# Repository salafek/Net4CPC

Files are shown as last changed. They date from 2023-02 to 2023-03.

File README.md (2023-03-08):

# Net4CPC
Net4CPC is an Ethernet interface for the [Amstrad CPC](https://www.cpcwiki.eu/index.php/CPC) range of computers.</br>
It is a stand alone implemetation of the Ethernet interface found on the [Cyboard](https://github.com/salafek/cyboard-for-cpc).</br>
It is supported by [SymbOS](http://symbos.de) and by [KCNet utilities](https://github.com/salafek/KCNet-software-for-Net4CPC) for CP/M.</br> 
</br>
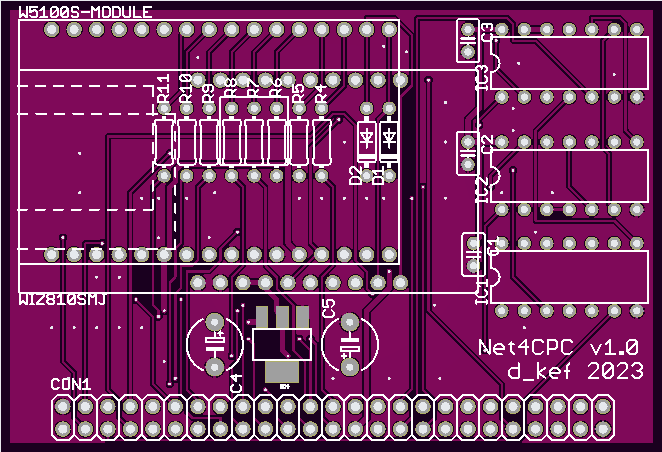
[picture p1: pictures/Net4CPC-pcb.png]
Net4CPC PCB

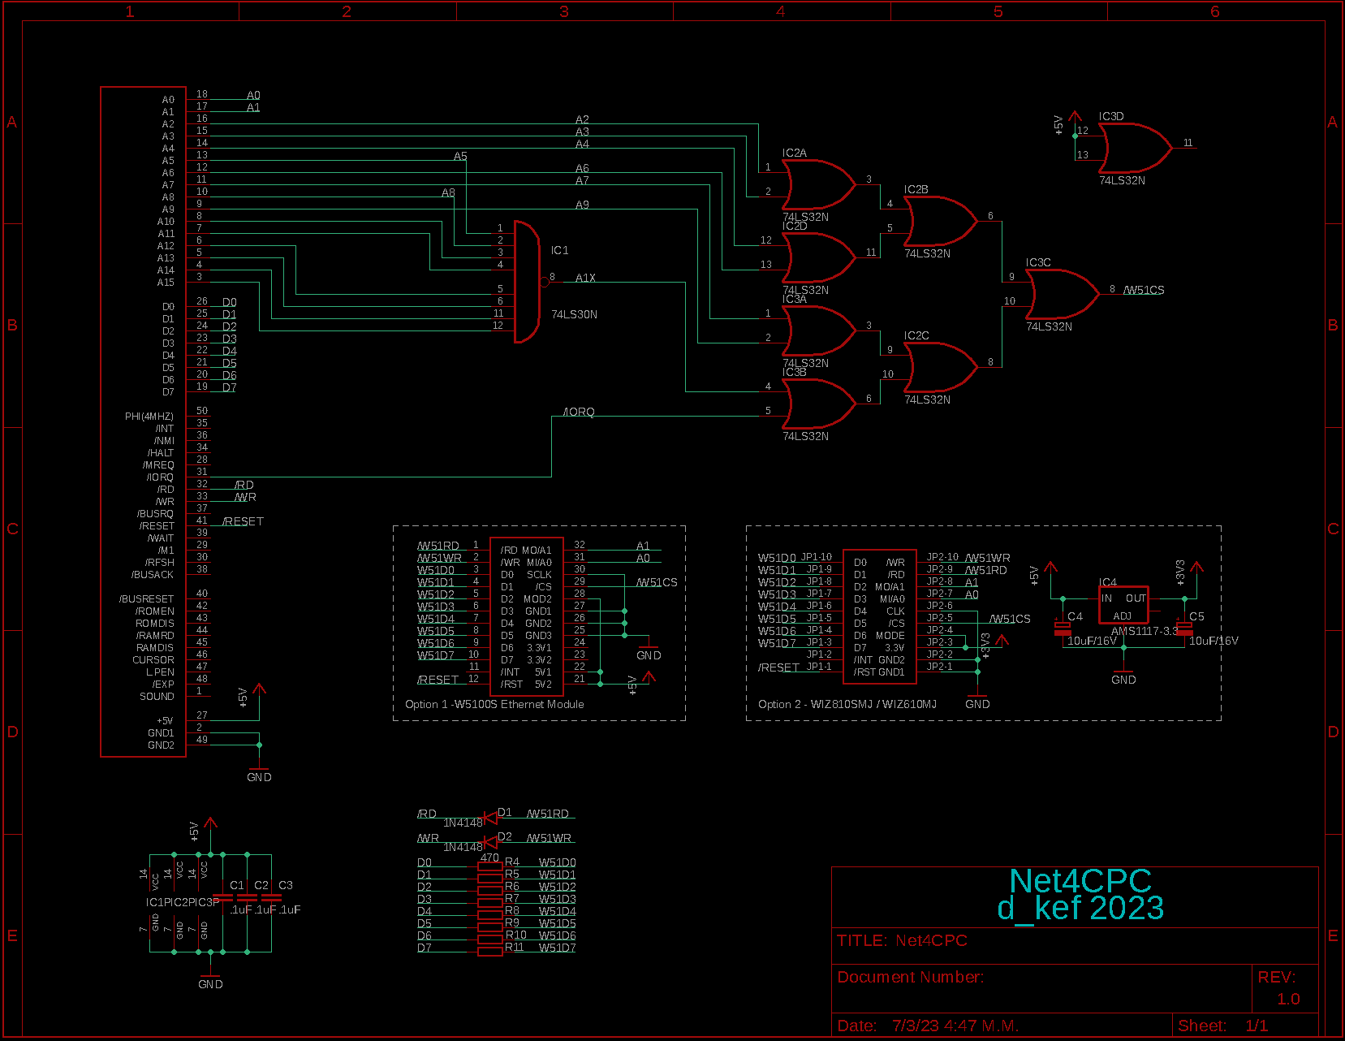
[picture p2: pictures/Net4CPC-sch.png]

## Notes
The interface has a [Mother X4](https://cpcrulez.fr/hardware-interface-mother_x4.htm) compatible connector.</br> 
The network module is based on the [WIZnet's W5100S](https://www.wiznet.io/product-item/w5100s/) embedded ethernet controller and works in indirect parallel bus mode.</br>
In this mode it needs 4 I/O ports:
- #FD20: MR - Common Register MR
- #FD21: IDM_ARH - Upper 8 bits Offset Address Register
- #FD22: IDM_ARL - Lower 8 bits Offset Address Register
- #FD23: IDM_DR - 8 Bits Data Register

A detailed description on how to program the module, with flow diagrams and programming examples, can be found at the WIZnet's official site:</br>
[W5100S TCP Function](https://docs.wiznet.io/Product/iEthernet/W5100S/Application-Note/tcp)</br>
[W5100S UDP Function](https://docs.wiznet.io/Product/iEthernet/W5100S/Application-Note/udp)</br>
[SOCKET-less Command](https://docs.wiznet.io/Product/iEthernet/W5100S/Application-Note/socket-less-command)</br>

The PCB has provision for 2 differrent types of Ethernet modules:
- A Chinese [W5100S module](https://www.aliexpress.com/w/wholesale-%22W5100S-Network-Module%22-parallel.html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) with an integrated 3.3V regulator.</br> W5100S module
- The original WIZnet's [W5100S](https://github.com/Wiznet/Hardware-Files-of-WIZnet/tree/master/05_Network_Module/WIZ810SMJ) or [W6100](https://github.com/Wiznet/Hardware-Files-of-WIZnet/tree/master/05_Network_Module/WIZ610MJ) modules.</br> 
## Build info
The schematic and layout were generated with Autodesk EAGLE 9.6.2 free edition</br>

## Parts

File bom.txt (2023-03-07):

Partlist

Part          Value                 Package               Digi-Key PN

C1            .1uF                  C025/C320             399-9871-1-ND
C2            .1uF                  C025/C320             399-9871-1-ND
C3            .1uF                  C025/C320             399-9871-1-ND
C4            10uF/16V              E5-06                 B41827A4105M-ND
C5            10uF/16V              E5-06                 B41827A4105M-ND
CON1          CPCBUS                HEADER R/A 50POS      732-5414-ND
D1            1N4148                DO35-7                2368-1N4148-ND
D2            1N4148                DO35-7                2368-1N4148-ND
IC1           74LS30N               DIL14                 296-3693-5-ND
IC2           74LS32N               DIL14                 296-1658-5-ND
IC3           74LS32N               DIL14                 296-1658-5-ND
IC4           AMS1117-3.3           SOT-223               4518-AMS1117-3.3TR-ND
R4            470                   0204/0207             MFR-25FRF52-470R-ND
R5            470                   0204/0207             MFR-25FRF52-470R-ND
R6            470                   0204/0207             MFR-25FRF52-470R-ND
R7            470                   0204/0207             MFR-25FRF52-470R-ND
R8            470                   0204/0207             MFR-25FRF52-470R-ND
R9            470                   0204/0207             MFR-25FRF52-470R-ND
R10           470                   0204/0207             MFR-25FRF52-470R-ND
R11           470                   0204/0207             MFR-25FRF52-470R-ND
W5100S-MODULE W5100S-NETWORK-MODULE W5100S-NETWORK-MODULE -
WIZ810SMJ     WIZ810SMJ / WIZ610MJ  WIZ810SMJ / WIZ610MJ  -

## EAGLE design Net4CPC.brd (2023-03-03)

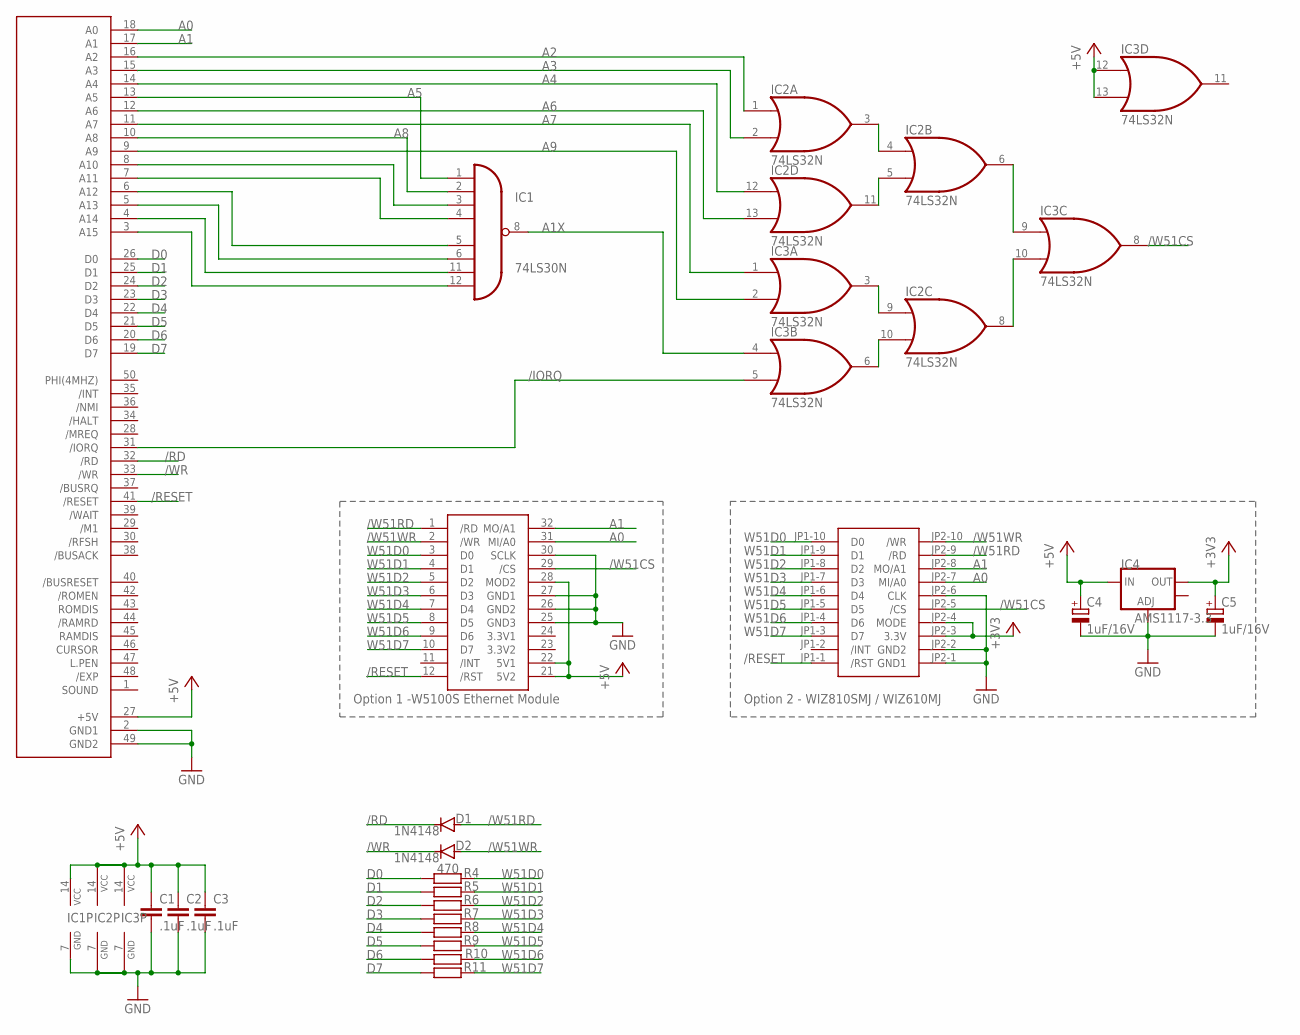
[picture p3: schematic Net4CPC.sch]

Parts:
C1, C2, C3: .1uF; C025-025X050
C4, C5: 1uF/16V; E5-6
CON1: CPCBUS; 2X25
D1, D2: 1N4148; DO35-7
IC1: 74LS30N; DIL14
IC2, IC3: 74LS32N; DIL14
IC4: AMS1117-3.3; SOT223
R4, R5, R6, R7, R8, R9, R10, R11: 470; 0204/7
W5100S-MODULE: W5100S-NETWORK-MODULENO-NAMES; W5100S-NETWORK-MODULE-NO-NAMES
WIZ810SMJ: WIZ810SMJ-NETWORK-MODULENO-NAMES; WIZ810SMJ-NETWORK-MODULE-NO-NAMES

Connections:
3.3V1: W5100S-MODULE.24 (3.3V1)
3.3V2: W5100S-MODULE.23 (3.3V2)
+3V3: C5.+, IC4.2 (OUT), WIZ810SMJ.JP2-3 (3.3V), WIZ810SMJ.JP2-4 (MODE)
+5V: C1.1, C2.1, C3.1, C4.+, CON1.27 (+5V), IC1.14 (VCC), IC2.14 (VCC), IC3.12 (I0), IC3.13 (I1), IC3.14 (VCC), IC4.3 (IN), W5100S-MODULE.21 (5V2), W5100S-MODULE.22 (5V1), W5100S-MODULE.28 (MOD2)
/IORQ: CON1.31 (/IORQ), IC3.5 (I1)
/RD: CON1.32 (/RD), D1.C
/RESET: CON1.41 (/RESET), W5100S-MODULE.12 (/RST), WIZ810SMJ.JP1-1 (/RST)
/W51CS: IC3.8 (O), W5100S-MODULE.29 (/CS), WIZ810SMJ.JP2-5 (/CS)
/W51RD: D1.A, W5100S-MODULE.1 (/RD), WIZ810SMJ.JP2-9 (/RD)
/W51WR: D2.A, W5100S-MODULE.2 (/WR), WIZ810SMJ.JP2-10 (/WR)
/WR: CON1.33 (/WR), D2.C
A0: CON1.18 (A0), W5100S-MODULE.31 (MI/A0), WIZ810SMJ.JP2-7 (MI/A0)
A1: CON1.17 (A1), W5100S-MODULE.32 (MO/A1), WIZ810SMJ.JP2-8 (MO/A1)
A1X: IC1.8 (O), IC3.4 (I0)
A2: CON1.16 (A2), IC2.1 (I0)
A3: CON1.15 (A3), IC2.2 (I1)
A4: CON1.14 (A4), IC2.12 (I0)
A5: CON1.13 (A5), IC1.1 (I0)
A6: CON1.12 (A6), IC2.13 (I1)
A7: CON1.11 (A7), IC3.1 (I0)
A8: CON1.10 (A8), IC1.2 (I1)
A9: CON1.9 (A9), IC3.2 (I1)
A10: CON1.8 (A10), IC1.3 (I2)
A11: CON1.7 (A11), IC1.4 (I3)
A12: CON1.6 (A12), IC1.5 (I4)
A13: CON1.5 (A13), IC1.6 (I5)
D0: CON1.26 (D0), R4.1
D1: CON1.25 (D1), R5.1
D2: CON1.24 (D2), R6.1
D3: CON1.23 (D3), R7.1
D4: CON1.22 (D4), R8.1
D5: CON1.21 (D5), R9.1
D6: CON1.20 (D6), R10.1
D7: CON1.19 (D7), R11.1
GND: C1.2, C2.2, C3.2, C4.-, C5.-, CON1.2 (GND1), CON1.49 (GND2), IC1.7 (GND), IC2.7 (GND), IC3.7 (GND), IC4.1 (ADJ), W5100S-MODULE.25 (GND3), W5100S-MODULE.26 (GND2), W5100S-MODULE.27 (GND1), W5100S-MODULE.30 (SCLK), WIZ810SMJ.JP2-1 (GND1), WIZ810SMJ.JP2-2 (GND2), WIZ810SMJ.JP2-6 (CLK)
unnamed: CON1.3 (A15), IC1.12 (I7)
unnamed: CON1.4 (A14), IC1.11 (I6)
unnamed: IC2.3 (O), IC2.4 (I0)
unnamed: IC2.5 (I1), IC2.11 (O)
unnamed: IC2.9 (I0), IC3.3 (O)
unnamed: IC2.10 (I1), IC3.6 (O)
unnamed: IC2.6 (O), IC3.9 (I0)
unnamed: IC2.8 (O), IC3.10 (I1)
W51D0: R4.2, W5100S-MODULE.3 (D0), WIZ810SMJ.JP1-10 (D0)
W51D1: R5.2, W5100S-MODULE.4 (D1), WIZ810SMJ.JP1-9 (D1)
W51D2: R6.2, W5100S-MODULE.5 (D2), WIZ810SMJ.JP1-8 (D2)
W51D3: R7.2, W5100S-MODULE.6 (D3), WIZ810SMJ.JP1-7 (D3)
W51D4: R8.2, W5100S-MODULE.7 (D4), WIZ810SMJ.JP1-6 (D4)
W51D5: R9.2, W5100S-MODULE.8 (D5), WIZ810SMJ.JP1-5 (D5)
W51D6: R10.2, W5100S-MODULE.9 (D6), WIZ810SMJ.JP1-4 (D6)
W51D7: R11.2, W5100S-MODULE.10 (D7), WIZ810SMJ.JP1-3 (D7)

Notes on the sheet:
Option 1 -W5100S Ethernet Module
Option 2 - WIZ810SMJ / WIZ610MJ

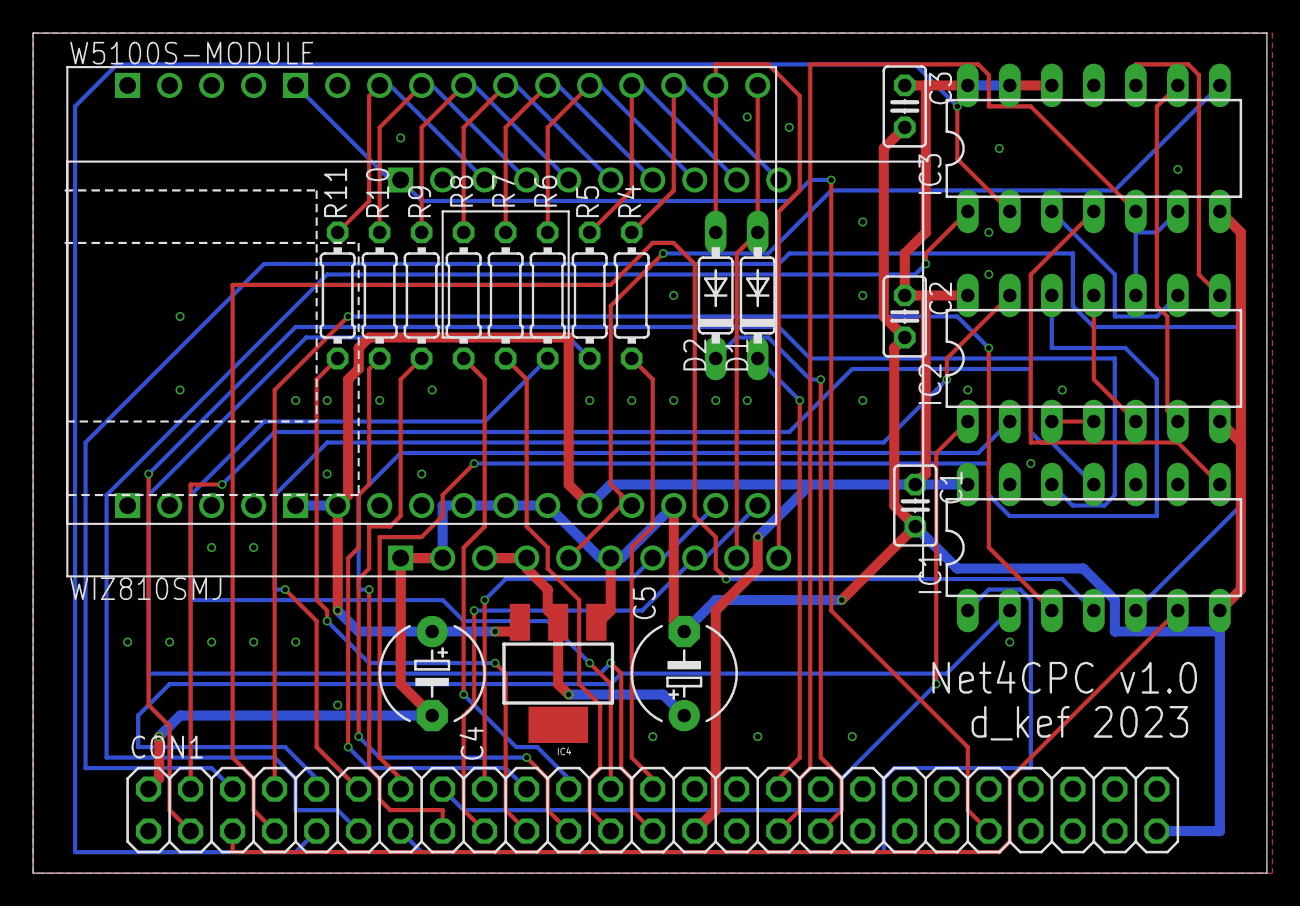
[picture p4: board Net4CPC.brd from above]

Board: 2 copper layers, 74.6 x 50.8 mm, 22 parts (0 on the bottom side), 49 nets.

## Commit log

2023-03-03 Add files via upload
    Added voltage value to electrolytic caps.
    [Net2CPC.sch]
2023-03-03 Add files via upload
    Added voltage value to electrolytic caps
2023-03-03 Add files via upload
    Changed IC1 type
    [Net2CPC.sch]
2023-03-03 Add files via upload
    Corrected file names
    [Net4CPC.brd, Net4CPC.sch]
2023-03-08 Add files via upload
    Electrolytic capacitors value change
    [Net4CPC.sch]
